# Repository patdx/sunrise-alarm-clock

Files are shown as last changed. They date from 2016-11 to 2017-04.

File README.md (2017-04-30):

# Sunrise Alarm Clock

## Media

[VIDEO: Testing Brightness Changes](https://youtu.be/-yi0IvZ5T_E)

### Schematic

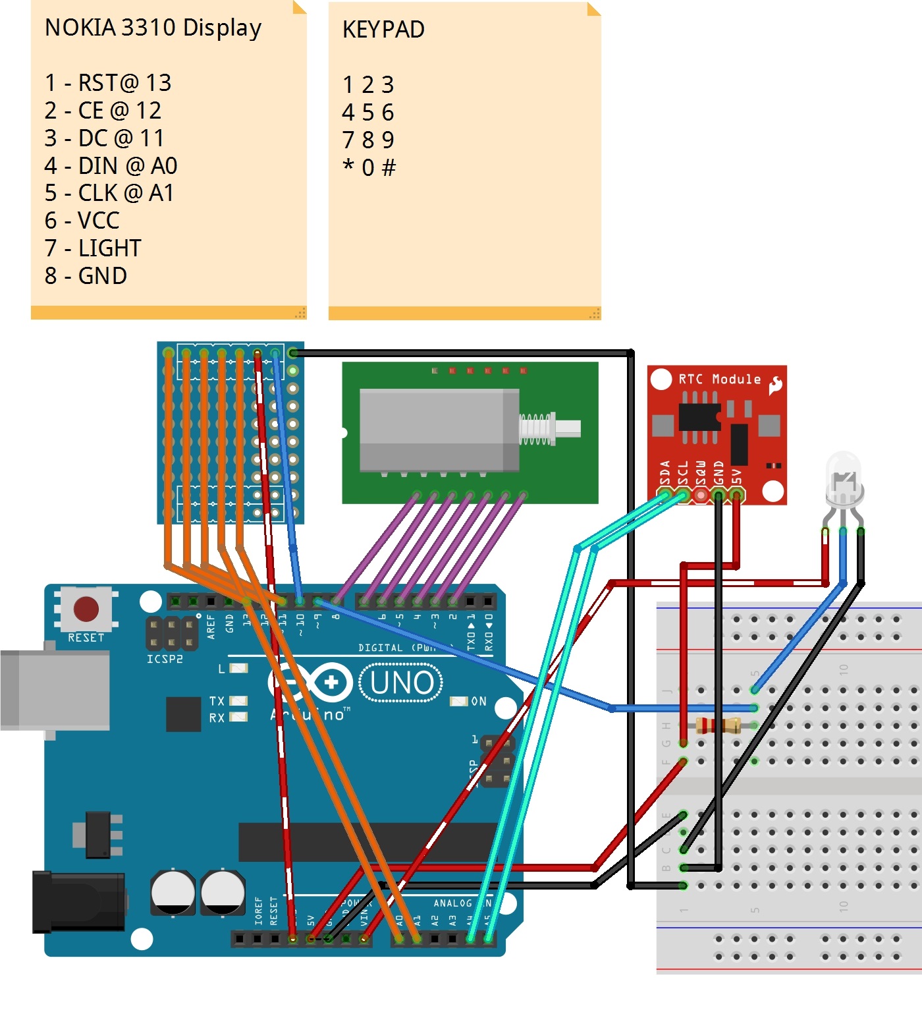
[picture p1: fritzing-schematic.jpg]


## Summary

This project was inspired by a persistently dark bedroom with a very small window.
I created an alarm clock (electronics and software) that simulated the sunrise.

It made waking up much more pleasant!

## Features

- Track current time, even without power, using battery powered RTC (real-time clock).
- LED lamp slowly fades into full brightness at the set alarm time, using pulse-width modulation applied to a gamma curve (to match human perception of brightness)
- Remember important settings, such as display contrast level and alarm time, by storing in EEPROM.
- Can set current time using Hour and Minute buttons
- Can set alarm time using Hour and Minute buttons
- Can toggle LCD contrast level.
- Can toggle alarm on/off.
- Can toggle LED lamp on/off.
- LCD screen has backlight on timer to be readable in the dark.

## Components

- Arduino Uno
- **UI**
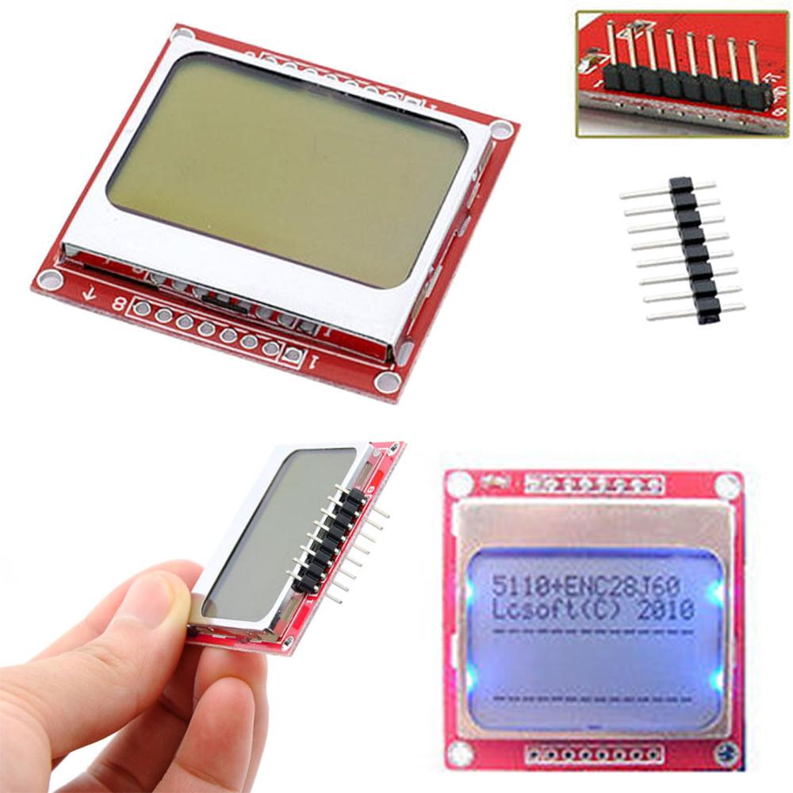
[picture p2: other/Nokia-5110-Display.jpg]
  - Nokia 5110 LCD Display <br>
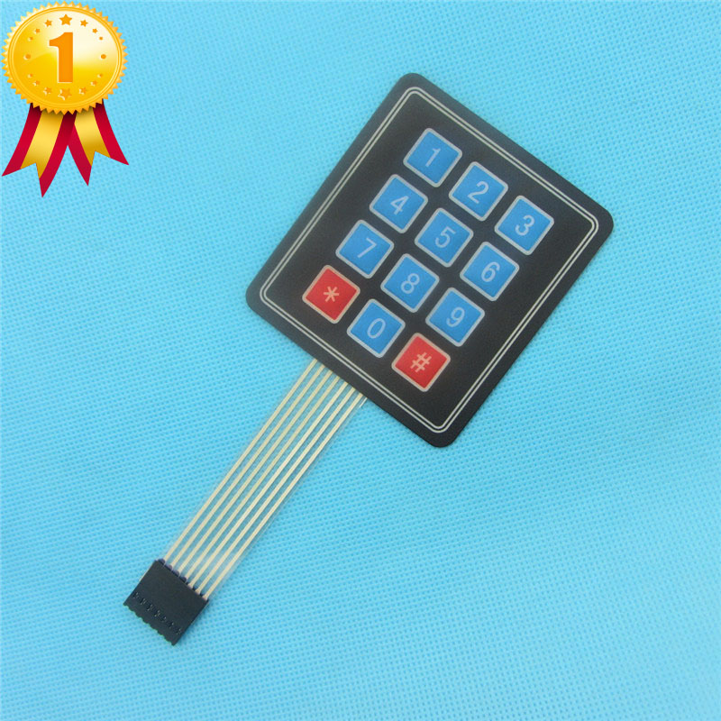
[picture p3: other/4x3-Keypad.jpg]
  - 4x3 Keypad <br>
- **Timekeeping**
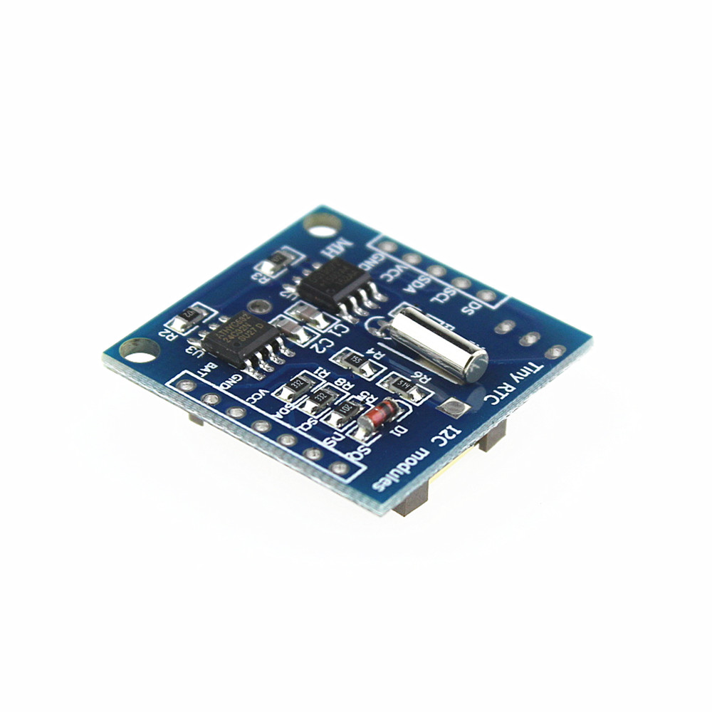
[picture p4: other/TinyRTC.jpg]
	- DS1307 TinyRTC <br>
- **LED**
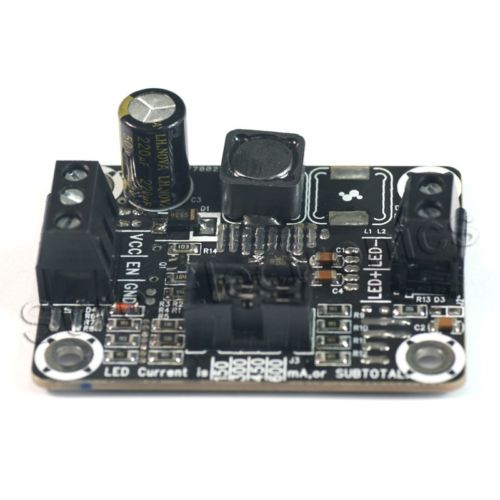
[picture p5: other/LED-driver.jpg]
	- 1500mA Buck Regulator LED Driver (supplies current to the LED and supports pulse-width modulation for dimming) <br>
	- ~10W LED Bulb (I recycled an LED bulb with a broken AC-DC power supply)

## Design

The resulting design looks roughly like this:



Nearly every available pin was required on the Arduino. Unfortunately I don't have a good picture of the device itself.

## Keypad

I created a mask for the 4x3 keypad, which gives a good idea of the features the Alarm Clock supports.

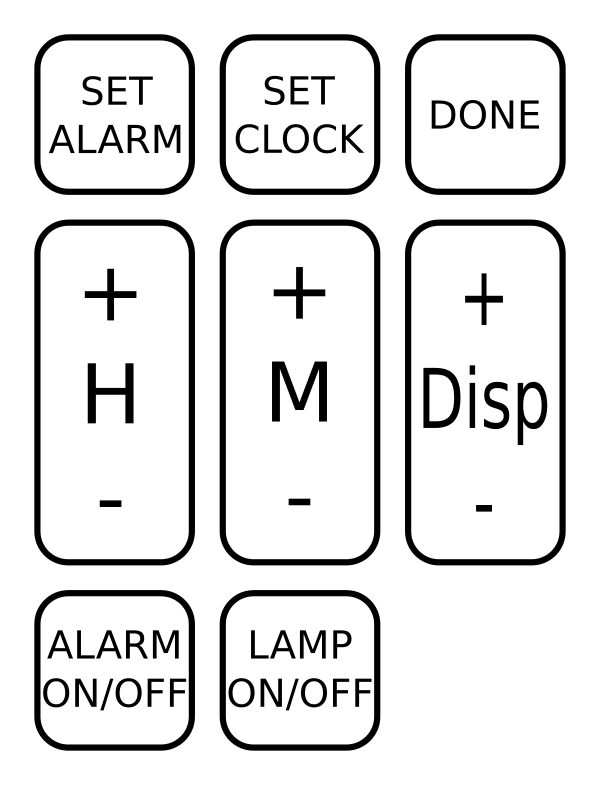
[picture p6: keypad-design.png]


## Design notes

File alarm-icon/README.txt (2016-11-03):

Icon created by me.

After converting with Image2Code.jar, it is currently stored in:

sunrise_functions.cpp

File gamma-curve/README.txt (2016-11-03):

This is Scilab code (similar to MATLAB)

Linear scaling of pulse-width results in uneven brightness change to the human eye. This code generates a nice conversion function, to allow for even brightness change. It is precalculated because the Arduino UNO is too busy for intense math. The resulting values go into:

sunrise_functions.cpp

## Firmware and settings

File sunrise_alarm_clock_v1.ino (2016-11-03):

#include <SPI.h>
#include <Adafruit_GFX.h>
#include <Adafruit_PCD8544.h>
#include <Time.h>
#include <TimerOne.h>

// For RTC:
#include <Wire.h>
#include <DS1307RTC.h>

// For data storage
#include <EEPROM.h>

#include "sunrise_functions.h"

#include <Keypad.h>

const byte ROWS = 4; // four rows
const byte COLS = 3; // three columns
char keys[ROWS][COLS] = {
  {'1', '2', '3'}, {'4', '5', '6'}, {'7', '8', '9'}, {'*', '0', '#'}};
byte rowPins[ROWS] = {2, 3, 4, 5}; // connect to the row pinouts of the keypad
byte colPins[COLS] = {6, 7, 8}; // connect to the column pinouts of the keypad

Keypad keypad = Keypad(makeKeymap(keys), rowPins, colPins, ROWS, COLS);

long previousMillis = 0;
int interval = 0;

const int backlight_timeout = 15; //time in seconds
int backlight_timer = 0; //


  void setup() {
    // Serial.begin(9600);
    initDevices(); // inits lamp, display, and clock/alarm
  }

  void loop() {
    // eventually this should get replaced with state machine
    // "what screen is showing right now?" logic
    if (last_sec != second()) {
      // runs if at least once second has elapsed
      // note: this could be a buggy implementation

      // showMessageOnDisplay("updating", 100); // debug command
      updateDisplay();
      last_sec = second(); // only update after updateDisplay();
    
    
    //check alarm once per second
    bool Alarm1_running_this_cycle = isAlarm1Running();
    if (Alarm1_running_this_cycle){
      double running_time = getAlarm1RunningTime();
      if (running_time <= Alarm1_duration){
        //alarm is current fading in
        int brightness = 1023.0*((running_time+1)/((double)Alarm1_duration+1.0));
        setLampGentle(brightness, 1);
      } else if (running_time <= Alarm1_timeout){
        setLampGentle(1023, 1);
      }
    }
    if (Alarm1_running_last_cycle && !Alarm1_running_this_cycle){
      //so alarm timeout just occurred or for some reason
      //alarm is not longer running
      //therefore...turn off the light!
      setLampGentle(0,1);  
    }
    Alarm1_running_last_cycle = Alarm1_running_this_cycle;
    
    if (backlight_timer < backlight_timeout){
      setDisplayBacklight(BACKLIGHT_DEFAULT_BRIGHTNESS);
      backlight_timer += 1;
    } else if (backlight_timer == backlight_timeout)
    {
      setDisplayBacklight(0);
      backlight_timer += 1; //so this doesn't get called over and over
    }
    
  }

    // serviceDisplay();

    unsigned long currentMillis = millis();

    if (currentMillis - previousMillis > interval) {
      previousMillis = currentMillis;
      serviceLamp();
    }
   
    

    char key = keypad.getKey();
    // char keystr[2] = "x";
    // keystr[0] = key;

    if (key) {
      setDisplayBacklight(BACKLIGHT_DEFAULT_BRIGHTNESS);
      backlight_timer = 0;
      if (key == '0') {
        // LAMP OFF
        //       setLampInstant(0);
        //       updateDisplay();
      }
      if (key == '*') {
        // LAMP TOGGLE
        if (!isAlarm1Running())
        {
          toggleLamp();
          //updateDisplay();
        } else {
          showMessageOnDisplay("Turn off alarm to toggle lamp.",1500);
        }
      }
      if (key == '#') {
        if (isAlarm1Running())
        {
        }
        
        toggleAlarm1();
        updateDisplay();
      }
      if (key == '1') {
		current_control_mode = CONTROL_SET_ALARM_TIME;
      }
      if (key == '2') {
		current_control_mode = CONTROL_SET_CLOCK_TIME;
      }
      if (key == '3') {
		current_control_mode = CONTROL_MAIN;
      }
      if (key == '4') {
		//H-
		if (current_control_mode == CONTROL_SET_ALARM_TIME)
		{
			Alarm1_hour -= 1;
			if (Alarm1_hour == -1)
			{
				Alarm1_hour = 23;
			}
			Alarm1_isAM = (Alarm1_hour < 12);
			EEPROM.write(EEPROM_ADDR_ALARM_HOUR,Alarm1_hour);
		}
		if (current_control_mode == CONTROL_SET_CLOCK_TIME)
		{
			int new_hour = hour()-1;
			if (new_hour == -1)
			{
				new_hour = 23;
			}
			setTime(new_hour, minute(), second(), 1, 1, 2014);
			RTC.set(now());
		}
		updateDisplay();
      }
      if (key == '5') {
		//H+
		if (current_control_mode == CONTROL_SET_ALARM_TIME)
		{
			Alarm1_hour += 1;
			if (Alarm1_hour == 24)
			{
				Alarm1_hour = 0;
			}
			Alarm1_isAM = (Alarm1_hour < 12);
			EEPROM.write(EEPROM_ADDR_ALARM_HOUR,Alarm1_hour);
		}
		if (current_control_mode == CONTROL_SET_CLOCK_TIME)
		{
			int new_hour = hour()+1;
			if (new_hour == 24)
			{
				new_hour = 0;
			}
			setTime(new_hour, minute(), second(), 1, 1, 2014);
			RTC.set(now());
		}
		updateDisplay();
      }
      if (key == '6') {
		// contrast+
		display_contrast++;
		display.setContrast(display_contrast);
		EEPROM.write(EEPROM_ADDR_LCD_CONTRAST,display_contrast);
		display.clearDisplay();
		display.print(display_contrast);
		display.display();
		delay(100);
      }
      if (key == '7') {
		//M-
		if (current_control_mode == CONTROL_SET_ALARM_TIME)
		{
			Alarm1_min -= 5;
			if (Alarm1_min < 0)
			{
				Alarm1_min = 55;
			}
			EEPROM.write(EEPROM_ADDR_ALARM_MIN,Alarm1_min);
		}
		if (current_control_mode == CONTROL_SET_CLOCK_TIME)
		{
			int new_min = minute()-1;
			if (new_min == -1)
			{
				new_min = 59;
			}
			setTime(hour(), new_min, second(), 1, 1, 2014);
			RTC.set(now());
		}
		updateDisplay();
      }
      if (key == '8') {
		//M+
		if (current_control_mode == CONTROL_SET_ALARM_TIME)
		{
			Alarm1_min += 5;
			if (Alarm1_min >= 60)
			{
				Alarm1_min = 0;
			}
			EEPROM.write(EEPROM_ADDR_ALARM_MIN,Alarm1_min);
		}
		if (current_control_mode == CONTROL_SET_CLOCK_TIME)
		{
			int new_min = minute()+1;
			if (new_min == 60)
			{
				new_min = 0;
			}
			setTime(hour(), new_min, second(), 1, 1, 2014);
			RTC.set(now());
		}
		updateDisplay();
      }
      if (key == '9') {
		// contrast-
		display_contrast--;
		display.setContrast(display_contrast);
		EEPROM.write(EEPROM_ADDR_LCD_CONTRAST,display_contrast);
		display.clearDisplay();
		display.print(display_contrast);
		display.display();
		delay(100);
      }
    }



    // DEBUG OPTIONS
    // if (key) {
    //   // showMessageOnDisplay(&key, 200); // this might not be address safe
    //   if (key == '0') {
    //     setLampInstant(0);
    //   }
    //   if (key == '1') {
    //     setLampInstant(1);
    //   }
    //   if (key == '2') {
    //     setLampInstant(2);
    //   }
    //   if (key == '3') {
    //     setLampInstant(3);
    //   }
    //   if (key == '4') {
    //     Timer1.setPeriod(2000);
    //     Timer1.start();
    //     setLampInstant(lamp_current_brightness);
    //     showMessageOnDisplay("2000 uS = 500 Hz", 200);
    //   }
    //   if (key == '5') {
    //     Timer1.setPeriod(3333);
    //     Timer1.start();
    //     setLampInstant(lamp_current_brightness);
    //     showMessageOnDisplay("3333 uS = 300 Hz", 200);
    //   }
    //   if (key == '6') {
    //     Timer1.setPeriod(5000);
    //     Timer1.start();
    //     setLampInstant(lamp_current_brightness);
    //     showMessageOnDisplay("5000 uS = 200 Hz", 200);
    //   }
    //   if (key == '7') {
    //     setLampGentle(0, 1);
    //   }
    //   if (key == '8') {
    //     setLampGentle(100, 1);
    //   }
    //   if (key == '9') {
    //     setLampGentle(1023, 1);
    //   }
    //   if (key == '*') {
    //     setLampInstant(1023);
    //   }
    // }
  }

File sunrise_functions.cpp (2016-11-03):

#include "sunrise_functions.h"

// GENERAL
void initDevices() {
  //initLamp();
  initDisplay();
  initClockAndAlarm();
}


enum ControlMode current_control_mode = CONTROL_MAIN;

//////////////////////////////////
// LAMP CONTROL
//////////////////////////////////

const int LAMP_PIN = 9;          // must be 9 or 10 to use Timer1
int lamp_current_brightness = 0; // from 0 to 1023
int lamp_target_brightness = 0;
int lamp_brightness_delta = 0; // number of pwm points per servicing
const int PROGMEM gamma[] = {0,1,1,1,1,1,1,1,1,1,1,1,1,1,1,1,1,1,2,2,2,2,2,2,2,2,2,2,2,3,3,3,3,3,3,3,3,3,3,4,4,4,4,4,4,4,4,5,5,5,5,5,5,5,6,6,6,6,6,6,6,7,7,7,7,7,7,8,8,8,8,8,8,9,9,9,9,9,10,10,10,10,10,11,11,11,11,11,12,12,12,12,12,13,13,13,13,13,14,14,14,14,15,15,15,15,16,16,16,16,17,17,17,17,18,18,18,18,19,19,19,19,20,20,20,21,21,21,21,22,22,22,22,23,23,23,24,24,24,25,25,25,25,26,26,26,27,27,27,28,28,28,29,29,29,30,30,30,31,31,31,32,32,32,33,33,33,34,34,35,35,35,36,36,36,37,37,37,38,38,39,39,39,40,40,40,41,41,42,42,42,43,43,44,44,44,45,45,46,46,47,47,47,48,48,49,49,50,50,50,51,51,52,52,53,53,53,54,54,55,55,56,56,57,57,58,58,58,59,59,60,60,61,61,62,62,63,63,64,64,65,65,66,66,67,67,68,68,69,69,70,70,71,71,72,72,73,73,74,74,75,75,76,77,77,78,78,79,79,80,80,81,81,82,83,83,84,84,85,85,86,86,87,88,88,89,89,90,91,91,92,92,93,93,94,95,95,96,96,97,98,98,99,99,100,101,101,102,103,103,104,104,105,106,106,107,108,108,109,109,110,111,111,112,113,113,114,115,115,116,117,117,118,119,119,120,121,121,122,123,123,124,125,125,126,127,127,128,129,130,130,131,132,132,133,134,134,135,136,137,137,138,139,139,140,141,142,142,143,144,145,145,146,147,148,148,149,150,150,151,152,153,154,154,155,156,157,157,158,159,160,160,161,162,163,164,164,165,166,167,167,168,169,170,171,171,172,173,174,175,175,176,177,178,179,180,180,181,182,183,184,185,185,186,187,188,189,190,190,191,192,193,194,195,195,196,197,198,199,200,201,201,202,203,204,205,206,207,208,209,209,210,211,212,213,214,215,216,217,217,218,219,220,221,222,223,224,225,226,227,227,228,229,230,231,232,233,234,235,236,237,238,239,240,241,242,242,243,244,245,246,247,248,249,250,251,252,253,254,255,256,257,258,259,260,261,262,263,264,265,266,267,268,269,270,271,272,273,274,275,276,277,278,279,280,281,282,283,284,285,286,287,288,289,290,291,292,294,295,296,297,298,299,300,301,302,303,304,305,306,307,308,309,311,312,313,314,315,316,317,318,319,320,321,322,324,325,326,327,328,329,330,331,332,334,335,336,337,338,339,340,341,343,344,345,346,347,348,349,351,352,353,354,355,356,357,359,360,361,362,363,364,366,367,368,369,370,371,373,374,375,376,377,379,380,381,382,383,385,386,387,388,389,391,392,393,394,395,397,398,399,400,402,403,404,405,406,408,409,410,411,413,414,415,416,418,419,420,421,423,424,425,426,428,429,430,431,433,434,435,437,438,439,440,442,443,444,446,447,448,449,451,452,453,455,456,457,459,460,461,463,464,465,466,468,469,470,472,473,474,476,477,478,480,481,482,484,485,487,488,489,491,492,493,495,496,497,499,500,501,503,504,506,507,508,510,511,513,514,515,517,518,519,521,522,524,525,526,528,529,531,532,533,535,536,538,539,541,542,543,545,546,548,549,551,552,553,555,556,558,559,561,562,564,565,566,568,569,571,572,574,575,577,578,580,581,583,584,586,587,589,590,592,593,595,596,597,599,600,602,603,605,606,608,610,611,613,614,616,617,619,620,622,623,625,626,628,629,631,632,634,635,637,639,640,642,643,645,646,648,649,651,653,654,656,657,659,660,662,664,665,667,668,670,671,673,675,676,678,679,681,683,684,686,687,689,691,692,694,695,697,699,700,702,704,705,707,708,710,712,713,715,717,718,720,721,723,725,726,728,730,731,733,735,736,738,740,741,743,745,746,748,750,751,753,755,756,758,760,761,763,765,767,768,770,772,773,775,777,778,780,782,784,785,787,789,790,792,794,796,797,799,801,803,804,806,808,809,811,813,815,816,818,820,822,823,825,827,829,830,832,834,836,838,839,841,843,845,846,848,850,852,854,855,857,859,861,863,864,866,868,870,872,873,875,877,879,881,882,884,886,888,890,892,893,895,897,899,901,903,904,906,908,910,912,914,915,917,919,921,923,925,927,928,930,932,934,936,938,940,942,943,945,947,949,951,953,955,957,959,960,962,964,966,968,970,972,974,976,978,979,981,983,985,987,989,991,993,995,997,999,1001,1004,1007,1010,1012,1014,1016,1018,1019,1020,1021,1022,1023};


void initLamp() {
  // pinMode(LAMP_PIN, OUTPUT);
  // TCCR1A |= _BV(COM1A1);
  // digitalWrite(LAMP_PIN, HIGH); //should enable pullup does this help?

  Timer1.initialize(2000); // 2000 = 500hz, 3333 = 300Hz (At 500 reaching limit
  // of resolution but flicker free)
  // Timer1.start(); //not sure if this is needed

  // So there appears to be some sort of glitch where running pwm() to init the
  // pin causes a LOW signal to be sent for a non-zero amount of time. Boo. From
  // what I gather, I really need to write all this Timer1 code by hand and have
  // a good way of debugging it. Bleurgh. In that case this solution is good
  // enough thank you.

  Timer1.pwm(LAMP_PIN, 0); // init at full brightness
  setLampInstant(1023); // tell my tracking code it's all full brightness
  setLampGentle(0, 5); // init fade out
  //  delay(200);
  // setLampInstant(0);       // sets to 0 brightness
}
void setLampPrivate(int brightness) {
  // this might be excessive but I am explicitly writing this
  // function so I know that the PWM feature isn't being used
  // when at 1023 or 0
  // if (brightness <= 0) {
  //   Timer1.disablePwm(LAMP_PIN);
  //   //Timer1.stop();
  //   digitalWrite(LAMP_PIN, HIGH);
  //   lamp_current_brightness = 0;
  // } else if (brightness >= 1023) {
  //   Timer1.disablePwm(LAMP_PIN);
  //   digitalWrite(LAMP_PIN, LOW);
  //   lamp_current_brightness = 1023;
  //   //Timer1.start();
  // } else {


  if(lamp_current_brightness != brightness){
    //if a difference is detected...then change brightness
	//read our PROGMEM table for adjusted brightness
	int gammabrightness = pgm_read_word(&gamma[brightness]);
    //Timer1.setPwmDuty(LAMP_PIN,1023 - brightness); // this command can only be used after initialized
    Timer1.setPwmDuty(LAMP_PIN,1023 - gammabrightness);
	int last_brightness = lamp_current_brightness;
    lamp_current_brightness = brightness;
    if(brightness == 0 || last_brightness == 0){
      //if lamp WAS off or has just BECOME off then refresh
      //lamp icon on screen
	  updateDisplay();  
    }
  }
}
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
